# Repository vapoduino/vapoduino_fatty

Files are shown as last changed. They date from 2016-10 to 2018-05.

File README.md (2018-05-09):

# Vapoduino Fatty

**NOTE:** This is a prototype which was made as a proof-of-concept. It is funcitonal, but there will not be any further development

This is an eralier prototype of the open source herbs vaporizer from [acidg/vape_model](https://github.com/acidg/vape_model).
It features a Bluetooth connection and an app, which can be found under [acidg/vape_app](https://github.com/acidg/vape_app).

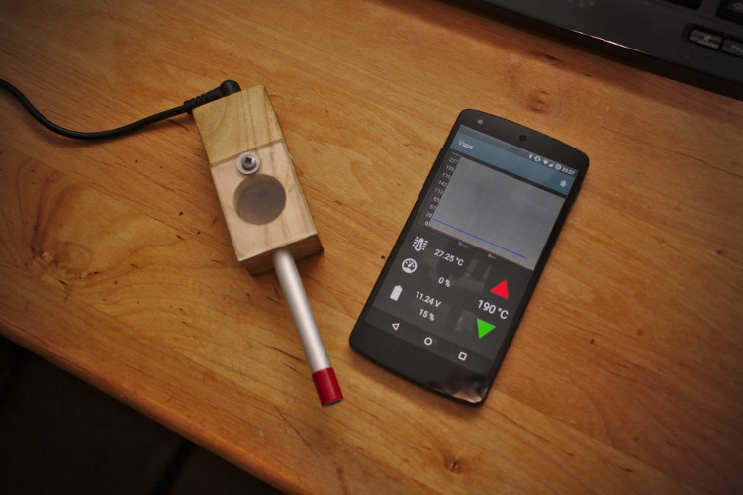
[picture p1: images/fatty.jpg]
Vapoduino Fatty


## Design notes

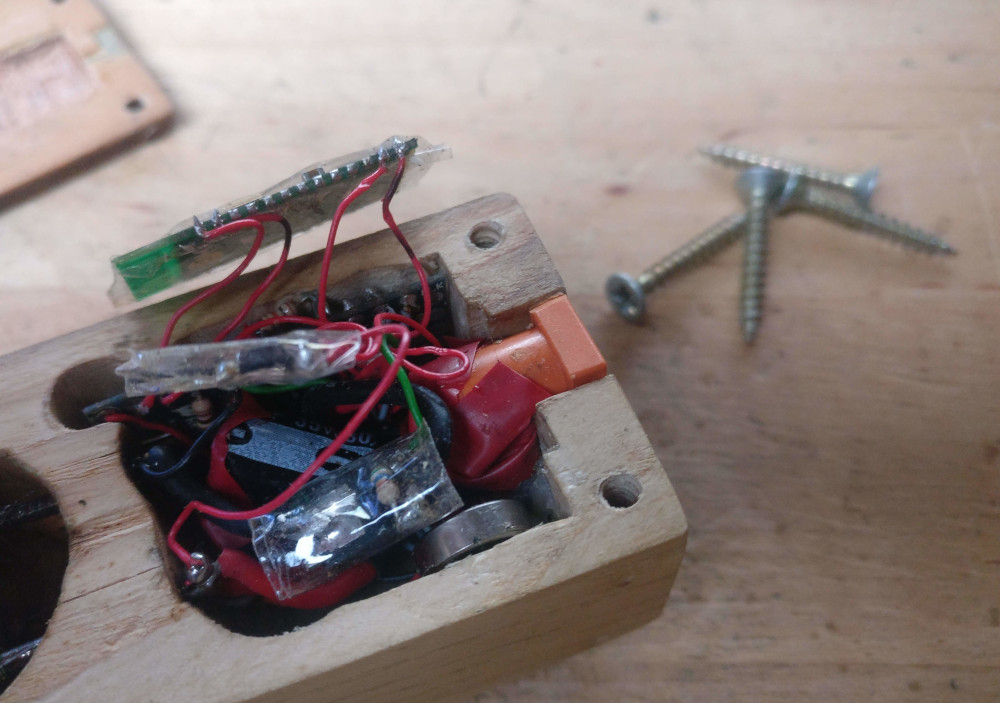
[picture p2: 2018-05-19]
images/electronics_bay.jpg

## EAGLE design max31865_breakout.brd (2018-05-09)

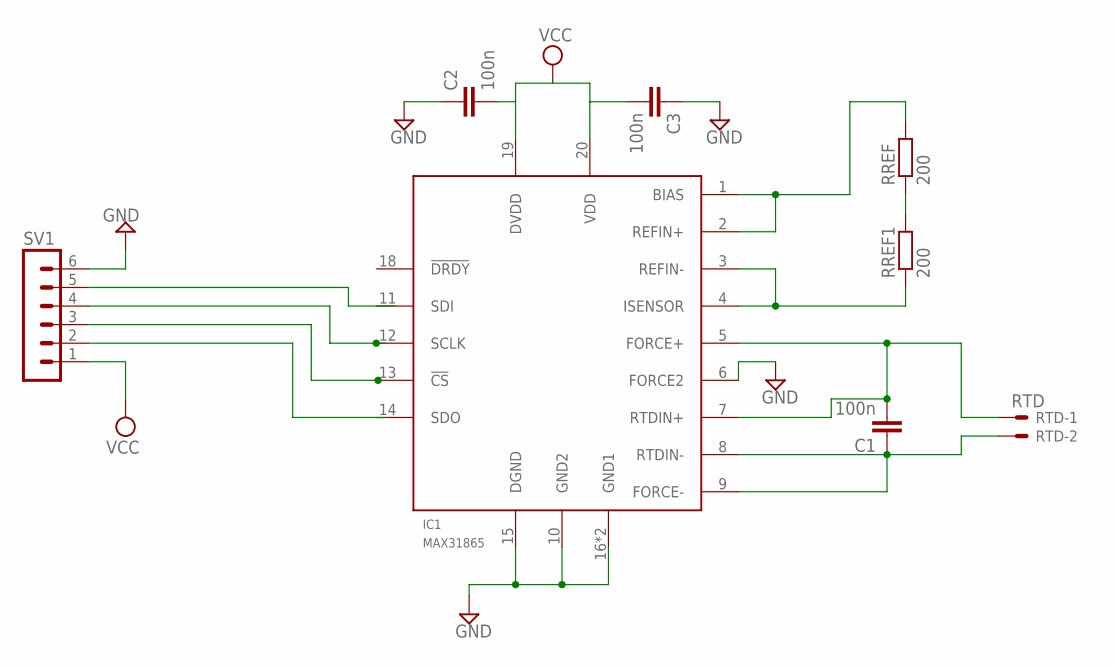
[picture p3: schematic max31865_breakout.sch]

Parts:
C1, C2, C3: 100n; C0805K
IC1: MAX31865; TQFN20-5X5
RREF, RREF1: 200; M1206
RTD: RTD; 22-23-2021
SV1: MA06-1

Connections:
CS: SV1.3
GND: C2.1, C3.1, IC1.6 (FORCE2), IC1.10 (GND2), IC1.15 (DGND), IC1.16 (GND1), IC1.EXP (GND1), SV1.6
unnamed: RREF.1, RREF1.2
REFIN+: IC1.1 (BIAS), IC1.2 (REFIN+), RREF.2
REFIN-: IC1.3 (REFIN-), IC1.4 (ISENSOR), RREF1.1
RTD+: C1.2, IC1.5 (FORCE+), IC1.7 (RTDIN+), RTD.1
RTD-: C1.1, IC1.8 (RTDIN-), IC1.9 (FORCE-), RTD.2
SCLK: IC1.12 (SCLK), SV1.4
SDI: SV1.5
SDO: SV1.2
VCC: C2.2, C3.2, IC1.19 (DVDD), IC1.20 (VDD), SV1.1

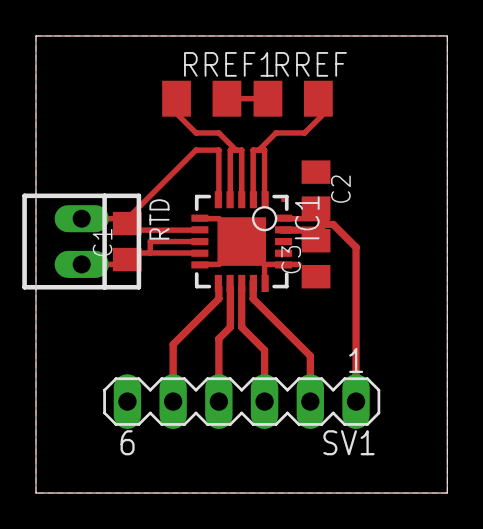
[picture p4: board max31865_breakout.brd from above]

Board: 2 copper layers, 22.8 x 25.4 mm, 8 parts (0 on the bottom side), 8 nets.

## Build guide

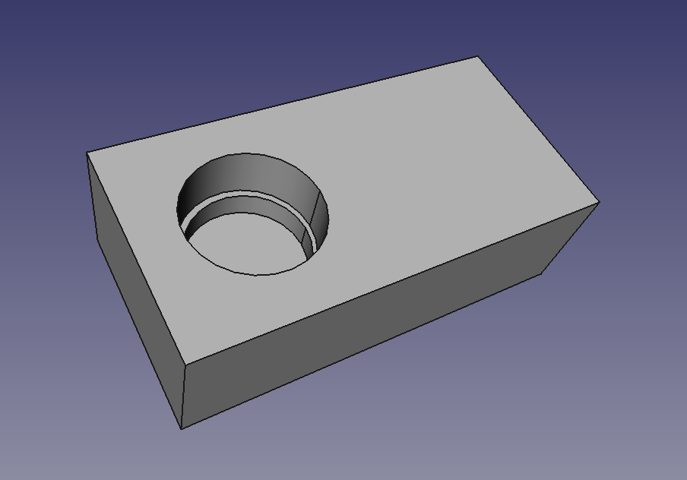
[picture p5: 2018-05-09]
images/step_03.png

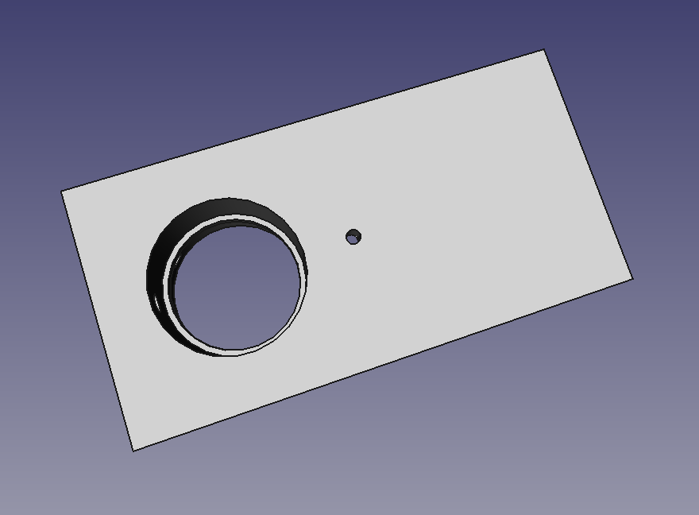
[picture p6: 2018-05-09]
images/step_12.png

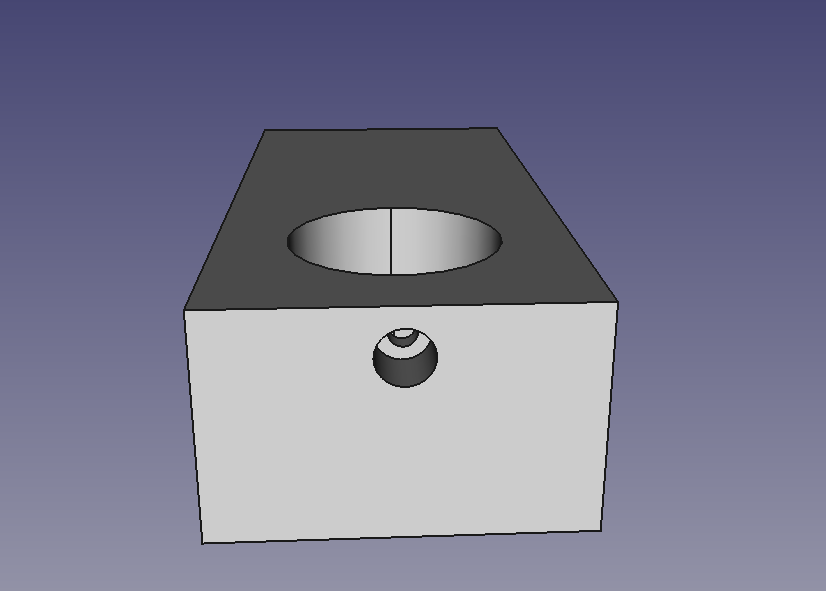
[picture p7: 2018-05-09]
images/step_08.png

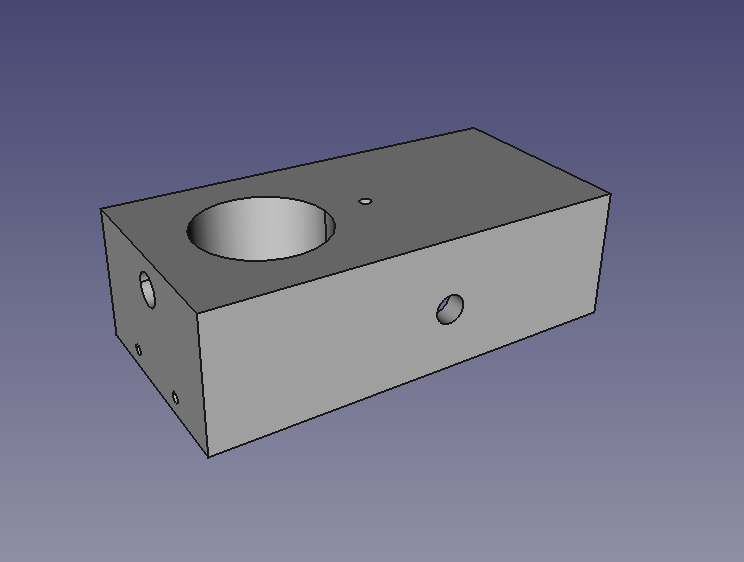
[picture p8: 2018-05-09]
images/step_13.png

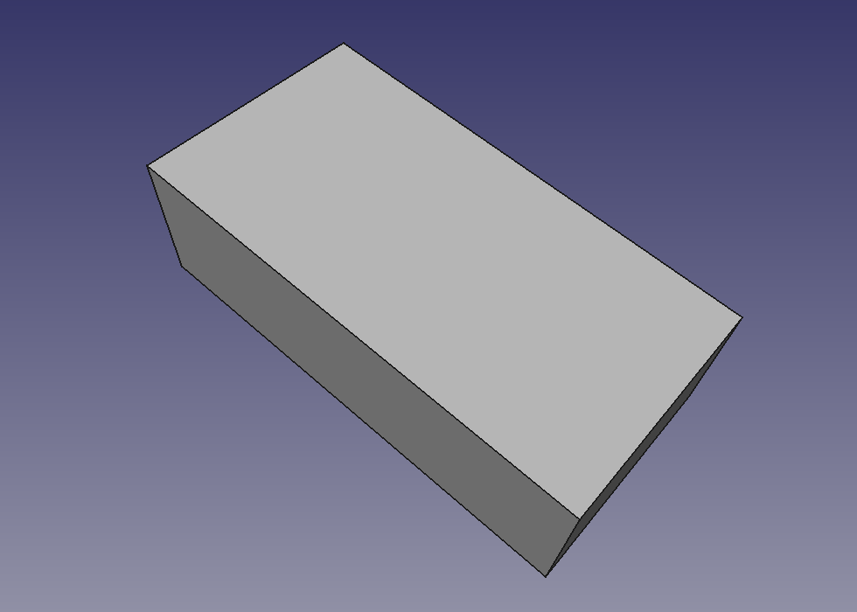
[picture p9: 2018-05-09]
images/step_01.png

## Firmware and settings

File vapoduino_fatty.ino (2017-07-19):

#include <Arduino.h>

/*
 * Created 04/28/2014 - vapoduino.ino
 *
 * Vapoduino - Arduino based controller for a Vaporizer.
 *
 * Copyright (C) 2014 Benedikt Schlagberger
 *
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
 */

#include <SoftwareSerial.h>

#define MOSFET_GATE_PIN 5
#define BUTTON_PIN 3
#define LED_PIN 6
#define VIBRATOR_PIN 9
#define BATTERY_PIN A3
#define BT_RX_PIN 8
#define BT_TX_PIN 7

//#define PID_P 19 // counter-"force"
//#define PID_I 12 // counter-offset
//#define PID_D 12 // dampen controlling, react on fast changes
#define PID_P_HEATING 3.6
#define PID_I_HEATING 0.2
#define PID_D_HEATING 4
#define MAX_HEATING_POWER 255

#define VOLTAGE_DIVIDER 0.01505277f
#define MAXIMUM_VOLTAGE 12.6f
#define MINIMUM_VOLTAGE 11.0f

#define STANDBY_TIMEOUT 1500
#define TEMPERATURE_EEPROM_ADDRESS 0
#define PID_P_EEPROM_ADDRESS 1
#define PID_I_EEPROM_ADDRESS 2
#define PID_D_EEPROM_ADDRESS 3

#include <PID_v1.h>
#include <EEPROM.h>

double temp, output, desired_temp;
double pid_p, pid_i, pid_d;
PID pid(&temp, &output, &desired_temp, pid_p, pid_i, pid_d, DIRECT);
SoftwareSerial bt_serial(BT_RX_PIN, BT_TX_PIN);
boolean new_cycle;
int cycles;
int too_much_draw_counter;

void setup() {
    Serial.begin(9600);
    bt_serial.begin(9600);

    Serial.println("#####################################");
    Serial.println("#####         VAPODUINO         #####");
    Serial.println("#####################################\n\n");

    // Set pinmodes
    pinMode(MOSFET_GATE_PIN, OUTPUT);
    pinMode(LED_PIN, OUTPUT);
    pinMode(BUTTON_PIN, INPUT);
    pinMode(VIBRATOR_PIN, OUTPUT);

    desired_temp = get_desired_temp();

    loadPID();

    // Setting up max31865
    while (!max_init()) {
        error("Could not initialize sensor!");
    }

    // Bugfix, don't know why...
    temp = max_get_temp();
    while (temp < 0) {
        // retrying, sometimes it takes some time
        error(" Reading negative temps... Retrying");
        temp = max_get_temp();
        Serial.print(temp);
        Serial.print(" ");
    }

    // Start PID control
    temp = max_get_temp();
    pid.SetMode(AUTOMATIC);

    new_cycle = true;
    too_much_draw_counter = 0;

    digitalWrite(LED_PIN, HIGH);
    vibrate_for_ms(500);
    digitalWrite(LED_PIN, LOW);
}

void loop() {
    temp = max_get_temp();

    digitalWrite(LED_PIN, LOW);
    digitalWrite(VIBRATOR_PIN, LOW);

    if (digitalRead(BUTTON_PIN) == HIGH) {
        // reset standby timeout
        cycles = 0;

        if (new_cycle) {
            heatUpChamber();

            new_cycle = false;
            pid = PID(&temp, &output, &desired_temp, pid_p, pid_i, pid_d, DIRECT);
            pid.SetOutputLimits(0, 255);
            pid.SetMode(AUTOMATIC);
        }

        pid.Compute();
        analogWrite(MOSFET_GATE_PIN, output);
        if (output == 255) {
            too_much_draw_counter++;
            if (too_much_draw_counter > 20) {
                digitalWrite(LED_PIN, HIGH);
                digitalWrite(VIBRATOR_PIN, HIGH);
            }
        } else {
            too_much_draw_counter = 0;
            digitalWrite(LED_PIN, LOW);
            digitalWrite(VIBRATOR_PIN, LOW);
        }
    } else {
        cycles++;

        // count till timeout
        if (cycles == STANDBY_TIMEOUT) {
            vibrate_for_ms(1000);
            cycles = 0;
        }
        pid.SetMode(MANUAL);
        output = 0;
        analogWrite(MOSFET_GATE_PIN, output);
        digitalWrite(LED_PIN, LOW);

        new_cycle = true;

        // debouncing the button
        delay(20);
    }
    printStatus();

    check_serial();

    delay(50);
}

void heatUpChamber() {
    // heat up chamber to desired_temp
    double heating_temp = desired_temp * 1.05;
    pid = PID(&temp, &output, &heating_temp, PID_P_HEATING, PID_I_HEATING, PID_D_HEATING, DIRECT);
    pid.SetOutputLimits(0, MAX_HEATING_POWER);
    pid.SetMode(AUTOMATIC);

    while (digitalRead(BUTTON_PIN) == HIGH && temp < desired_temp) {
        temp = max_get_temp();

        digitalWrite(LED_PIN, HIGH);
        pid.Compute();
        analogWrite(MOSFET_GATE_PIN, output);
        printStatus();

        delay(50);
    }

    if (temp > desired_temp) {
        vibrate_for_ms(200);
    }
}

void printStatus() {
    int raw = analogRead(A3);
//    Serial.print("Desired Temp: ");
//    Serial.print((int) desired_temp);
//    Serial.print(", Temp: ");
//    Serial.print(temp);
//    Serial.print(", P: ");
//    Serial.print(pid_p);
//    Serial.print(", I: ");
//    Serial.print(pid_i);
//    Serial.print(", D: ");
//    Serial.print(pid_d);
//    Serial.print(", Heat: ");
//    Serial.print(output);
//    Serial.print(", Volts: ");
//    Serial.print(raw * VOLTAGE_DIVIDER);
//    Serial.print(", Percents: ");
//    Serial.println(get_battery_percents(raw * VOLTAGE_DIVIDER));

    bt_serial.print("s;");
    bt_serial.print(temp);
    bt_serial.print(";");
    bt_serial.print(output);
    bt_serial.print(";");
    bt_serial.print(raw * VOLTAGE_DIVIDER);
    bt_serial.print(";");
    bt_serial.println(get_battery_percents(raw * VOLTAGE_DIVIDER));
}

void error(String message) {
    Serial.println(message);
    digitalWrite(MOSFET_GATE_PIN, LOW);
}

void check_serial() {
    if (bt_serial.available()) {
        digitalWrite(MOSFET_GATE_PIN, LOW);
        char command = bt_serial.read();
        switch (command) {
        case 't':
            while (!bt_serial.available());
            command = bt_serial.read();
            switch (command) {
            case '=':
                while (!bt_serial.available());
                set_desired_temp(bt_serial.read());
            case '?':
                bt_serial.print("t;");
                bt_serial.println(EEPROM.read(TEMPERATURE_EEPROM_ADDRESS));
                break;
            default:
                bt_serial.println("Unknown Command");
            }
            break;
        case 'p':
            while (!bt_serial.available());
            command = bt_serial.read();
            switch (command) {
            case '=':
                check_PID();
            case '?':
                bt_serial.print("p;");
                bt_serial.print((float) EEPROM.read(PID_P_EEPROM_ADDRESS) / 10);
                bt_serial.print(";");
                bt_serial.print((float) EEPROM.read(PID_I_EEPROM_ADDRESS) / 10);
                bt_serial.print(";");
                bt_serial.println((float) EEPROM.read(PID_D_EEPROM_ADDRESS) / 10);
                break;
            default:
                bt_serial.println("Unknown Command");
            }
        default:
            bt_serial.println("Unknown Command");
        }
    }
}

void check_PID() {
    while (!bt_serial.available());
    byte p = bt_serial.read();
    while (!bt_serial.available());
    byte i = bt_serial.read();
    while (!bt_serial.available());
    byte d = bt_serial.read();

    setPID(p, i, d);
}

float get_desired_temp() {
    return (float) EEPROM.read(TEMPERATURE_EEPROM_ADDRESS);
}

void loadPID() {
    pid_p = (double) EEPROM.read(PID_P_EEPROM_ADDRESS) / 10;
    pid_i = (double) EEPROM.read(PID_I_EEPROM_ADDRESS) / 10;
    pid_d = (double) EEPROM.read(PID_D_EEPROM_ADDRESS) / 10;
}

void setPID(byte p, byte i, byte d) {
    EEPROM.write(PID_P_EEPROM_ADDRESS, p);
    EEPROM.write(PID_I_EEPROM_ADDRESS, i);
    EEPROM.write(PID_D_EEPROM_ADDRESS, d);

    loadPID();
}

int get_battery_percents(float voltage) {
    int percent = (voltage - MINIMUM_VOLTAGE) / (MAXIMUM_VOLTAGE - MINIMUM_VOLTAGE) * 100;
    return percent < 0 ? 0 : percent;
}

void set_desired_temp(byte new_temp) {
    EEPROM.write(TEMPERATURE_EEPROM_ADDRESS, new_temp);
    desired_temp = (float) new_temp;
}

void delay_with_interrupt(int time, int interrupting_button_state) {
    int counter = 0;
    while (digitalRead(BUTTON_PIN) != interrupting_button_state & counter < time) {
        counter++;
        delay(1);
    }
    // debounce
    delay(20);
}

void vibrate_for_ms(int ms) {
    digitalWrite(VIBRATOR_PIN, HIGH);
    delay(ms);
    digitalWrite(VIBRATOR_PIN, LOW);
}

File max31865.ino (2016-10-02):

#include <Arduino.h>

/*
 * Created 05/30/2014 - max31865.ino
 * 
 * Vapoduino - Arduino based controller for a Vaporizer.
 * 
 * Copyright (C) 2014 Benedikt Schlagberger
 *
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
 */

#include <SPI.h>
 
/*******************************************************************************
 **                          CONFIGURATION PARAMETERS                         **
 *******************************************************************************/

#define DRDY_PIN 4
#define CS_PIN 10
#define REFERENCE_RESISTOR 400
#define PT_RESISTANCE 100
#define USE_AVERGAGE_TEMP 1
#define AVG_VALUES_COUNT 5

/**
 * Configuration of the MAX31865 from MSB to LSB:
 * BIT      FUNCTION            ASSIGNMENT
 *  7       VBIAS               0=OFF            1=ON
 *  6       Conversion Mode     0=Normally OFF   1=AUTO
 *  5       1-Shot              0= -             1=1-Shot
 *  4       3-Wire              0=2- or 4-Wire   1=3-wire
 * 3,2      Faultdetection      set both to 0
 *  1       Fault Status Clear  set to 1
 *  0       50/60Hz filter      0=60Hz           1=50Hz
 */
#define MAX31865_CONFIG 0b11000011

//*******************************************************************************


// Registers defined in Table 1 on page 12 of the data sheet
#define CONFIGURATION_REGISTER 0x00
#define RTD_MSB_REGISTER 0x01
#define RTD_LSB_REGISTER 0x02
#define HIGH_FAULT_THRESHOLD_MSB_REGISTER 0x03
#define HIGH_FAULT_THRESHOLD_LSB_REGISTER 0x04
#define LOW_FAULT_THRESHOLD_MSB_REGISTER 0x05
#define LOW_FAULT_THRESHOLD_LSB_REGISTER 0x06
#define FAULT_STATUS_REGISTER 0x07

#define READ_MODE 0x00
#define WRITE_MODE 0x80

// Selfclearing bits for the configuation register
#define START_1_SHOT 0x20
#define CLEAR_FAULT_STATUS 0x02

// Constants for Callendar-Van Dusen equation
static float a = 0.00390830;
static float b = -0.0000005775;
static float c = -0.00000000000418301;

#if (USE_AVERGAGE_TEMP)
static boolean use_average_temp = true;
#else
static boolean use_average_temp = false;
#endif

// Array for averaging the reads
int values[AVG_VALUES_COUNT];
int counter;

boolean max_init() {
    // Configuring in- and outputs
    pinMode(DRDY_PIN, INPUT);
    pinMode(CS_PIN, OUTPUT);
    
    // Deselecting MAX31865
    digitalWrite(CS_PIN, HIGH);
  
    // Configuring SPI
    SPI.begin();
    SPI.setDataMode(SPI_MODE1);
//    SPI.setClockDivider(SPI_CLOCK_DIV128);
    
    // Wait for MAX31865 to set up
    delay(200);
    
    // Initial configuration of MAX31865
    if (!_send_config(MAX31865_CONFIG)) {
        Serial.println("Communication failed!");
        Serial.println(_spi_read(CONFIGURATION_REGISTER), BIN);
        return false;
    }
    
    // fill average data
    for (int i = 0; i < AVG_VALUES_COUNT; i++) {
        max_get_temp();
    }
    
    // Setting up average calculation
    counter = 0;
    
    // TODO: Set threshold for temperature reading
    
//    _spi_write(LOW_FAULT_THRESHOLD_MSB_REGISTER, 0x00);
//    _spi_write(LOW_FAULT_THRESHOLD_LSB_REGISTER, 0x00);
//    _spi_write(HIGH_FAULT_THRESHOLD_MSB_REGISTER, 0xFF);
//    _spi_write(HIGH_FAULT_THRESHOLD_LSB_REGISTER, 0xFF);
    return true;
}

/**
 * Reads the rtd value from the MAX31865 chip and calculates the temperature by using
 * the Callendar-Van Dusen equation for approximation.
 */
float max_get_temp() {
    // read value
    byte lsb = _spi_read(RTD_LSB_REGISTER);
    unsigned int rtd_value = _spi_read(RTD_MSB_REGISTER) << 7;
    
    // shift out the fault bit
    rtd_value += (lsb >> 1);
    
    if ((lsb & 1)) {
        Serial.print("\nFault Detected! RTD value: ");
        Serial.println(rtd_value);
        delay(100);
        byte fault = _spi_read(FAULT_STATUS_REGISTER);
        
        _resolve_fault(fault);
        
        // return NaN
        return rtd_value;
    } else {
        // check if data is valid
        if (rtd_value == 0) {
            Serial.println("MAX31865 is stuck or not responding. Trying to reconfigure.");
            if (!_send_config(MAX31865_CONFIG)) {
                Serial.println("Communication failed!");
                Serial.println(_spi_read(CONFIGURATION_REGISTER), BIN);
                while(true);
            }
            // return NaN
            return 0.0 / 0.0;
        }
        
        if (use_average_temp) {
            rtd_value = _calculate_avg(rtd_value);
        }
        
        return _calculate_temp(rtd_value);
    }
}

/**
 * Sends the given value to the given registeraddress via SPI.
 */
void _spi_write(byte address, byte value) {
    digitalWrite(CS_PIN, LOW);
    SPI.transfer(WRITE_MODE + address);
    SPI.transfer(value);
    digitalWrite(CS_PIN, HIGH);
}

/**
 * Reads from the given registeraddress via SPI and returns
 * the value.
 */
byte _spi_read(byte address) {
    digitalWrite(CS_PIN, LOW);
    SPI.transfer(READ_MODE + address);
    byte value = SPI.transfer(0x00);
    digitalWrite(CS_PIN, HIGH);
    digitalWrite(8, LOW);
    return value;
}

/** 
 * Sends the given configuration to the MAX31865.
 */
boolean _send_config(byte configuration) {
    _spi_write(CONFIGURATION_REGISTER, configuration);
    
    byte returned_value = _spi_read(CONFIGURATION_REGISTER);
    
    // exclude self clearing bit (fault status clear)
    if ((returned_value & 0b11111101) == configuration) {
      return true;
    }
}

/**
 * Calculates the temperature from the given rtd value by using the 
 * Callendar-Van Dusen equation for approximation.
 */ 
float _calculate_temp(int rtd_value) {    
    // calculate recistance of RTD
    float resistance = (((float) rtd_value) * ((float) REFERENCE_RESISTOR)) / 32768;
    
    // Use Callendar-Van Dusen equation for approximation
    float temp = -PT_RESISTANCE * a
            + sqrt(PT_RESISTANCE * PT_RESISTANCE * a * a - 4 * PT_RESISTANCE * b * (PT_RESISTANCE - resistance));
    temp /= (2 * PT_RESISTANCE * b);

//    float temp = rtd_value / 32 - 256;
    return temp;
}
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

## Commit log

2016-07-17 shuting down heat, when command is received
2016-07-18 removing standby, adding battery percents to output
2016-07-18 addign pid change via serial commands
2017-07-19 enabling change of pid with bt app
2018-05-09 Adding schematics and PCB for MAX31865 breakout board
    [max31865_breakout.brd, max31865_breakout.sch]
2018-05-18 adding fritzing schematic
    [schematic.fzz]
2018-05-18 adding annotated schematic
    [schematic.fzz]

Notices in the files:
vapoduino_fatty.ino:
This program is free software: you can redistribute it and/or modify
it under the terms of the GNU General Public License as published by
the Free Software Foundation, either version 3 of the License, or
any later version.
